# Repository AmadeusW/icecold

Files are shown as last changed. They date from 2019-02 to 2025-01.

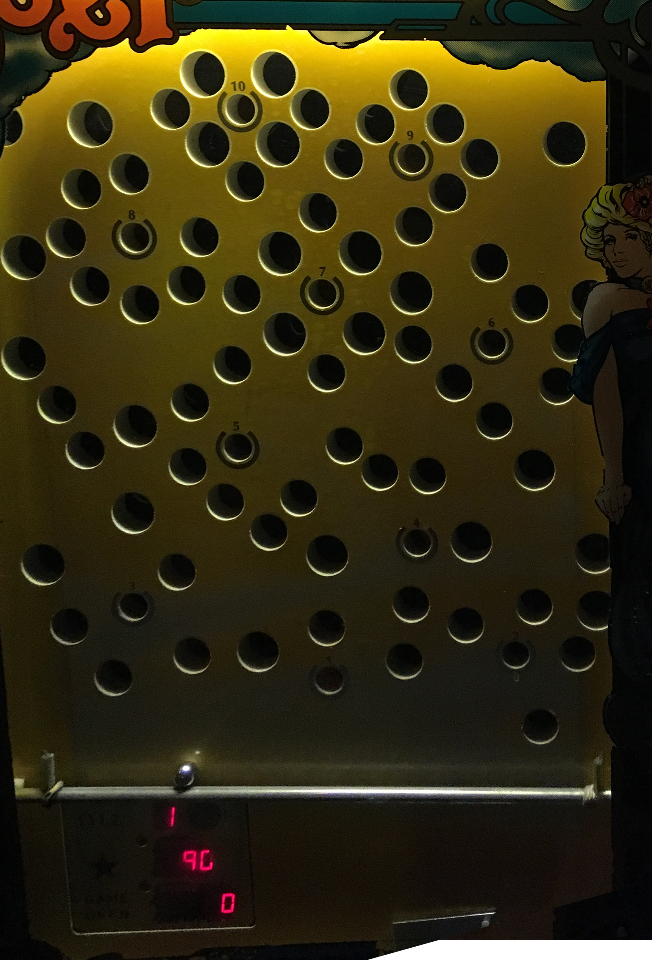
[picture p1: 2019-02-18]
web-prototype/holes.jpg

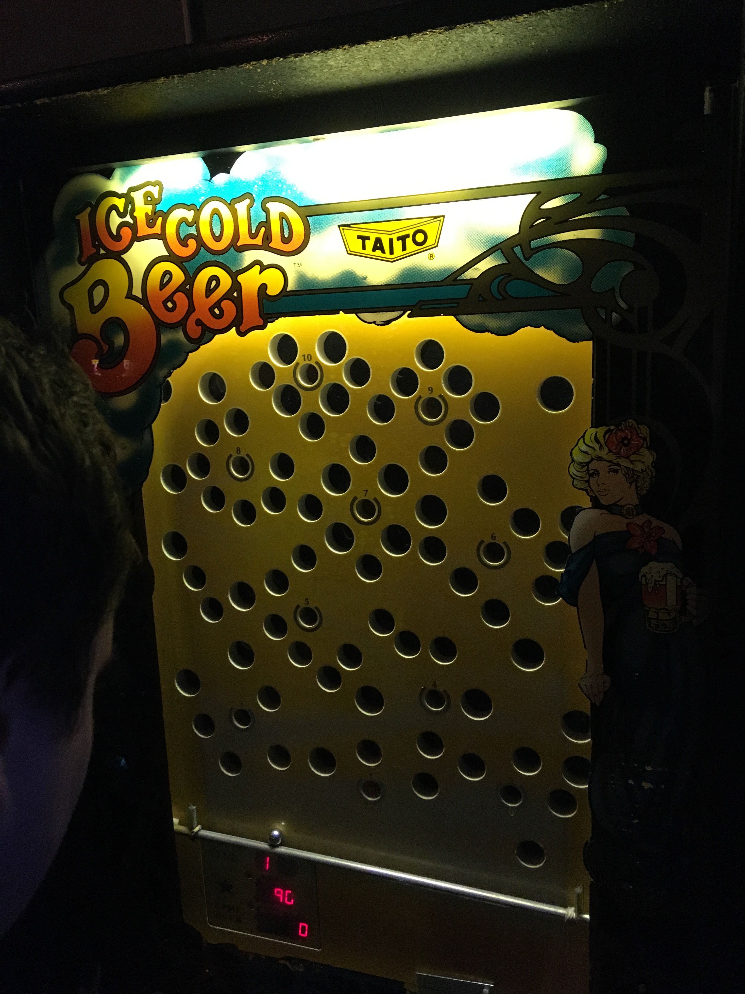
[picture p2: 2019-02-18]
misc/orignal photo.JPG

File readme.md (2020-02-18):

# Ice Cold Beer

**Ice Cold Beer** is an 1983 arcade by Taito.
Read more at [arcade-museum.com](https://www.arcade-museum.com/game_detail.php?game_id=10592)
See [picture](https://raw.githubusercontent.com/AmadeusW/icecold/master/misc/orignal%20photo.JPG)

# DIY Arcade

I'm building a physical arcade inspired by Ice Cold Beer.
See the [`program`](https://github.com/AmadeusW/icecold/tree/master/program) directory for microcontroller code and `printing` directory for 3D printed parts

# Virtual rendition

[Play now](https://amadeusw.github.io/icecold/web-prototype)

### Objective

* Insert the ball into the highlighted socket
* 🍺

### Controls

| Left | Right | |
|-|-|-|
| ↕ W/S | up/down ↕ | *Classic* |
| ↕ W/S | U/J ↕ | *Narrow* |
| ↕ W/S | I/J ↕ | *Narrow* |
| ↕ D/S | K/J ↕ | *VIM* |

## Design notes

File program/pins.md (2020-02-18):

# Pins

## Input

* 2 - Joystick L
* 2 - Joystick R
* 1 - Sensor Scored
* 1 - Sensor Lost
* 6 - Limiters

## Output

* 7 - Motor driver
* 2 - shift register
* ? - RGB strand

### Shift register
* 10 - Lives indicator
* 10 - Level indicator
* 10 - Target LEDs

### Parallel to Serial for input
* 1 - Sensor scored
* 1 - Sensor Lost
* 6 - Limiters

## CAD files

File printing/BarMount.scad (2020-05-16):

Gap = 0.2;
$fn = 72;

BarMount();

module BarMount() {
    RodThickness = 1.75 + Gap;
    RodDepth = 13.85; // Measured 13.10, but let's keep it a bit wider
    
    BearingDiameter = 8.0;
    BearingLength = 15;
    
    ConnectorShift = 0.3;
    
    ConnectorWidth = RodThickness+8;
    ConnectorDepth = RodDepth+5;
    
    CornerRadius = 1;
    
    intersection() {
        translate([0,0,ConnectorShift])
            cube([200,200,BearingDiameter - 2 * ConnectorShift], center=true);
        difference() {
            union () {
                rotate([0,-90,0])
                    cylinder(r = BearingDiameter/2, h = BearingLength);
                
                rotate([0,-90,0])
                    cylinder(r = BearingDiameter/2,
                             h = 5);
                
                linear_extrude(height=BearingDiameter, center=true)
                    offset(r=CornerRadius)
                        polygon([[CornerRadius, -ConnectorWidth/2 + CornerRadius],
                                 [ConnectorDepth - CornerRadius,
                                  -ConnectorWidth/2 + CornerRadius],
                                 [ConnectorDepth - CornerRadius,
                                  ConnectorWidth/2 - CornerRadius],
                                 [CornerRadius,
                                  ConnectorWidth/2 - CornerRadius]]);
            }
            
            rotate([0,0,2])
                union () {
                    translate([ConnectorDepth/2,0,0])
                        cube([RodDepth, RodThickness, 100], center = true);
            }
        }
    }    
}

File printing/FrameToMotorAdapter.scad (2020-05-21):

Gap = 0.2;
$fn = 72;

FrameToMotorAdapter();

module FrameToMotorAdapter() {
    Padding = 3.0;

    MotorInnerRadius = 13.0;
    MotorBraceRadius = MotorInnerRadius + Padding;

    SupportHeight = 6.0;
    MotorRadius = 26.0;

    HeadDiameter = 11.0;
    HeadHeight = 4.5 + Gap;

    ThreadDiameter = 6.6 + Gap; // I measured 6.2, but RodToBearingCoupling uses 6.5 for a snug fit
    ThreadHeight = 2.0;

    FrameAdapterWidth = HeadDiameter + 2*Padding;
    FrameAdapterLength = 32;
    FrameAdapterHeight = ThreadHeight + HeadHeight;

    BearingAdapterOffset = MotorRadius + FrameAdapterHeight; // Center of the rod
    BearingAdapterShift = 0;

    MountingNutOffset = 20.4;
    MountingNutRadius = 2.1; // actually 1.925, so 2.1 includes a gap

    ToTheSky = 50;

    union() {
        // Frame adapter
        difference() {
            cube([FrameAdapterLength, FrameAdapterWidth, FrameAdapterHeight]);

            // Volume of the nut head
            translate([0, Padding, ThreadHeight])
                cube([FrameAdapterLength, HeadDiameter, HeadHeight]);

            // Volume of the nut thread
            translate([0, Padding + (HeadDiameter - ThreadDiameter)/2, 0])
                cube([FrameAdapterLength, ThreadDiameter, ThreadHeight]);
        }

        // Motor housing adapter
        rotate([0, -90, 0])
        translate([BearingAdapterOffset, FrameAdapterWidth/2, -FrameAdapterLength])
        difference() {
            union()
            {
                // Resting arm
                translate([-BearingAdapterOffset/2, 0, 0])
                linear_extrude(height = SupportHeight, center = true)
                    polygon(points = [
                    [-BearingAdapterOffset/2, -FrameAdapterWidth/2],
                    [BearingAdapterOffset/2, -MotorRadius],
                    [BearingAdapterOffset/2, MotorRadius],
                    [-BearingAdapterOffset/2, FrameAdapterWidth/2],
                    ]);
            }
            union() {
                // Volume of motor housing
                cylinder(r = MotorRadius, h=SupportHeight, center=true);
            }
        }

        // Motor adapter
        rotate([0, -90, 0])
        translate([BearingAdapterOffset, FrameAdapterWidth/2, -BearingAdapterShift +SupportHeight/2])
        difference() {
            union()
            {
                // Bearing adapter
                difference()
                {
                    cylinder(r = MotorBraceRadius, h=SupportHeight, center=true);
                    // Remove top half (-Padding)
                    translate([-Padding, -ToTheSky/2, -ToTheSky/2])
                        cube([ToTheSky, ToTheSky, ToTheSky]);
                }
                
                // Connection to frame adapter
                p1 = RRTangent([BearingAdapterOffset/2,
                                -(MountingNutOffset+MountingNutRadius*.5)],
                               [-BearingAdapterOffset/2, -FrameAdapterWidth/2],
                               MountingNutRadius + Padding, 0, 1);

                p2 = RRTangent([BearingAdapterOffset/2,
                                (MountingNutOffset+MountingNutRadius*0.5)],
                               [-BearingAdapterOffset/2, FrameAdapterWidth/2],
                               MountingNutRadius + Padding, 0, -1);

                translate([-BearingAdapterOffset/2, 0, 0])
                linear_extrude(height = SupportHeight, center = true)
                    polygon(points = [
                    [-BearingAdapterOffset/2, -FrameAdapterWidth/2],
                    p1,
                    [BearingAdapterOffset/2,-(MountingNutOffset+MountingNutRadius*.5)],
                    [BearingAdapterOffset/2,(MountingNutOffset+MountingNutRadius*.5)],
                    p2,
                    [-BearingAdapterOffset/2, FrameAdapterWidth/2],
                    ]);

                // Mounting nut support
                translate([0, MountingNutOffset, 0])
                hull()
                {
                    translate([0, -MountingNutRadius/2, 0])
                        cylinder(r = MountingNutRadius + Padding, h=SupportHeight, center=true);
                    translate([0, MountingNutRadius/2, 0])
                        cylinder(r = MountingNutRadius + Padding, h=SupportHeight, center=true);
                }
                translate([0, -MountingNutOffset, 0])
                hull()
                {
                    translate([0, -MountingNutRadius/2, 0])
                        cylinder(r = MountingNutRadius + Padding, h=SupportHeight, center=true);
                    translate([0, MountingNutRadius/2, 0])
                        cylinder(r = MountingNutRadius + Padding, h=SupportHeight, center=true);
                }
            }
            union() {
                // Volume of motor
                translate([0, 0, 0])
                    cylinder(r = MotorInnerRadius + Gap, h=SupportHeight, center=true);

                // Mounting nuts
                translate([0, MountingNutOffset, 0])
                hull()
                {
                    translate([0, -MountingNutRadius/2, 0])
                        cylinder(r = MountingNutRadius, h=SupportHeight, center=true);
                    translate([0, MountingNutRadius/2, 0])
                        cylinder(r = MountingNutRadius, h=SupportHeight, center=true);
                }
                    
                translate([0, -MountingNutOffset, 0])
                hull()
                {
                    translate([0, -MountingNutRadius/2, 0])
                        cylinder(r = MountingNutRadius, h=SupportHeight, center=true);
                    translate([0, MountingNutRadius/2, 0])
                        cylinder(r = MountingNutRadius, h=SupportHeight, center=true);
                }
            }
        }
    }
}

// find p that is r1 from p1 and on a line that
// passes r1 from p1 and p2 from p2.
function RRTangent(p1, p2, r1, r2, s) =
     let(dx = (p2[0] - p1[0]))
     let(dy = (p2[1] - p1[1]))
     let(distance2 = dx*dx + dy*dy)
     let(distance = sqrt(distance2))
     let(nx = dx / distance)
     let(ny = dy / distance)
     let(cosA = (r1-r2)/distance)
     let(sinA = sqrt(1-cosA*cosA))
        [p1[0] + (cosA * r1) * nx - s * (sinA * r1) * ny,
         p1[1] + (cosA * r1) * ny + s * (sinA * r1) * nx];

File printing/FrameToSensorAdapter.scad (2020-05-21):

Gap = 0.2;
$fn = 72;

FrameToSensor();

module FrameToSensor() {
    Padding = 3.0;

    HeadDiameter = 11.0;
    HeadHeight = 4.5 + Gap;

    ThreadDiameter = 6.6 + Gap; // I measured 6.2, but RodToBearingCoupling uses 6.5 for a snug fit
    ThreadHeight = 2.0;

    FrameAdapterWidth = HeadDiameter + 2*Padding;
    FrameAdapterLength = 32;
    FrameAdapterHeight = ThreadHeight + HeadHeight;

    MotorRadius = 26.0;
    BearingAdapterOffset = MotorRadius + FrameAdapterHeight;
    BearingAdapterShift = 0;

    MountRadius = 1.0; // it's a 2mm screw
    MountDistance = 12.65;
    MountOffsetFromCenter = MountDistance / 2;
    MountHeight = FrameAdapterHeight + MountRadius + Padding; // As low as possible

    Width = MountDistance + (MountRadius*2 + Padding)*2;
    Depth = 4; // arbitrary
    Height = Width + FrameAdapterHeight;
    ToTheSky = 50;

    union() {
        // Frame adapter
        difference() {
            cube([FrameAdapterLength, FrameAdapterWidth, FrameAdapterHeight]);

            // Volume of the nut head
            translate([0, Padding, ThreadHeight])
                cube([FrameAdapterLength + Gap, HeadDiameter, HeadHeight]);

            // Volume of the nut thread
            translate([0, Padding + (HeadDiameter - ThreadDiameter)/2, 0])
                cube([FrameAdapterLength + Gap, ThreadDiameter, ThreadHeight]);
        }

        // Sensor adapter
        rotate([0, -90, 0])
        translate([0, FrameAdapterWidth/2, Depth/2])
        difference() {
            union()
            {
                // Connection to frame adapter
                linear_extrude(height = Depth, center = true)
                    polygon(points = [
                    [0, -FrameAdapterWidth/2],
                    [Height/2, -Width/2],
                    [Height/2, Width/2],
                    [0, FrameAdapterWidth/2],
                    ]);
            }
            union() {
                // Volume of mount 1
                translate([MountHeight, -MountOffsetFromCenter, 0])
                hull()
                {
                    translate([0, -MountRadius/2, 0])
                        cylinder(r = MountRadius + Gap, h=ToTheSky, center=true);
                    translate([0, MountRadius/2, 0])
                        cylinder(r = MountRadius + Gap, h=ToTheSky, center=true);
                }

                // Volume of mount 2
                translate([MountHeight, MountOffsetFromCenter, 0])
                hull()
                {
                    translate([0, -MountRadius/2, 0])
                        cylinder(r = MountRadius + Gap, h=ToTheSky, center=true);
                    translate([0, MountRadius/2, 0])
                        cylinder(r = MountRadius + Gap, h=ToTheSky, center=true);
                }
            }
        }
    }
}

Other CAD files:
printing/NutToMotorSupport.scad
printing/FrameBearingAdapter.scad
printing/FrameToBearingLAdapter.scad
printing/Guide.scad
printing/RodConnect.scad
printing/RodCoupling.scad
printing/RodToMotorCoupling.scad
printing/dependencies/Pulley_T-MXL-XL-HTD-GT2_N-tooth.scad
printing/obsolete/FrameBearingAdapter.scad
printing/obsolete/prototypes.scad
printing/prototypes.scad

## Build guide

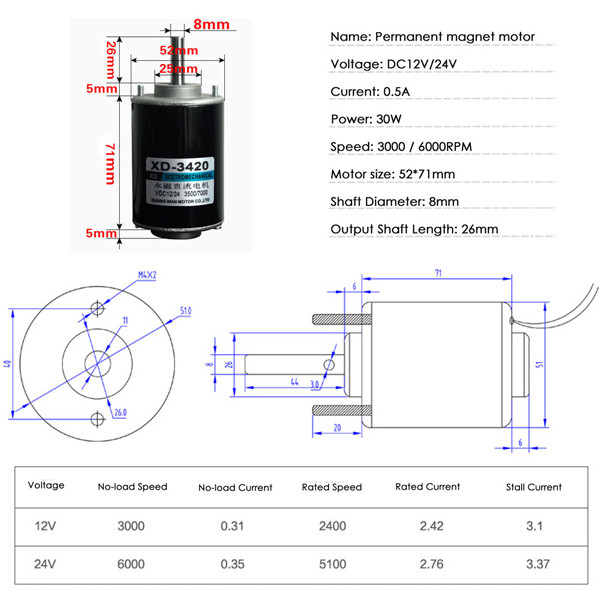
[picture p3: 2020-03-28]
printing/dependencies/xd-3420 dc motorjpg.jpg

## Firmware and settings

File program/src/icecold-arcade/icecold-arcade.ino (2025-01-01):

// Entry point for the code running on the microcontroller

#include "../common/composition.h"
#include "../common/GameController.h"
#include "../common/GameEngine.h"
#include "../common/GameState.h"

#include "../common/module.h"
#include "../common/modules/LedModule.h"

GameEngine* engine;

void setup() {
    // Example usage
    LedModule ledModule1(13);
    LedModule ledModule2(14);
    Module* modules[] = {&ledModule1, &ledModule2};
    Composition composition(modules, 2);
    GameController controller;
    GameState state;
    engine = new GameEngine(composition, controller, state);
    engine->setup();
}

void loop() {
    engine->loop();
}

int main()
{
    setup();
    while (true) {
        loop();
    }
}

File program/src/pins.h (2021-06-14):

#ifndef pins_h
#define pins_h

#include "Arduino.h"

#define PinMotorAIn1 1
#define PinMotorAIn2 1
#define PinMotorPWMA 1
#define PinMotorBIn1 1
#define PinMotorBIn2 1
#define PinMotorPWMB 1
#define PinMotorSTBY 0
#define PinJoyAUp 4 // green
#define PinJoyADown 5 // yellow
#define PinJoyBUp 6 // blue
#define PinJoyBDown 7 // yellow
#define PinSerialClock 8 // orange
#define PinSerialLatch 9 // orange
#define PinBallAtTarget 10 // white
#define PinBallAtBottom 11 // red
#define PinSerialData 12 // green
#define PinDebugLed 13
#define PinRange0Enable 16 // Yellow
#define PinRange1Enable 17 // Yellow
#define PinI2CData 18 // White
#define PinI2CClock 19 // Orange
// Future:
// #define PinServo X

#endif

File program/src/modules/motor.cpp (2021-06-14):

#include "Arduino.h"
#include "motor.h"
#include "../pins.h"

void Motor::Setup()
{
    pinMode(PinMotorAIn1, OUTPUT);
    pinMode(PinMotorAIn2, OUTPUT);
    pinMode(PinMotorPWMA, OUTPUT);
    pinMode(PinMotorSTBY, OUTPUT);

    digitalWrite(PinMotorSTBY, HIGH);

    Serial.println("Setup complete: Motor");
}

void Motor::Output(int tick)
{
    if (this->speedLeft == 0)
    {
        digitalWrite(PinMotorAIn1, HIGH);
        digitalWrite(PinMotorAIn2, HIGH);
    }
    else if (this->speedLeft > 0)
    {
        digitalWrite(PinMotorAIn1, HIGH);
        digitalWrite(PinMotorAIn2, LOW); 
        analogWrite(PinMotorPWMA, this->speedLeft);
    }
    else
    {
        digitalWrite(PinMotorAIn1, LOW);
        digitalWrite(PinMotorAIn2, HIGH); 
        analogWrite(PinMotorPWMA, -(this->speedLeft));
    }

    if (this->speedRight == 0)
    {
        digitalWrite(PinMotorBIn1, HIGH);
        digitalWrite(PinMotorBIn2, HIGH);
    }
    else if (this->speedRight > 0)
    {
        digitalWrite(PinMotorBIn1, HIGH);
        digitalWrite(PinMotorBIn2, LOW); 
        analogWrite(PinMotorPWMB, this->speedRight);
    }
    else
    {
        digitalWrite(PinMotorBIn1, LOW);
        digitalWrite(PinMotorBIn2, HIGH); 
        analogWrite(PinMotorPWMB, -(this->speedRight));
    }
}

void Motor::Brake()
{
    this->speedLeft = 0;
    this->speedRight = 0;
}

void Motor::MoveLeft(bool up, int speed)
{
    this->speedLeft = up ? speed : -speed;
}

void Motor::MoveRight(bool up, int speed)
{
    this->speedRight = up ? speed : -speed;
}

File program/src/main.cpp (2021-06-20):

#include "Arduino.h"
#include "pins.h"
#include "handler.h"
#include "state.h"
#include "composition.h"

// Define externs declared in state.h
State state = uninitialized;
int turn = 0;
Composition composition;

void setup()
{
  Serial.begin(115200); // set up debugging
  while (! Serial) { delay(1); }
  Serial.println("Hello World!");

  Serial.println("Composing modules...");
  composition.Compose(); // Compose modules and handlers
  Serial.println("Setting up modules...");
  composition.Setup(); // Setup all modules and handlers
  Serial.println("Setup complete.");
  delay(50);
  state = idle; // running
}

void updateState()
{
    Handler* handler = composition.GetHandler(state);
    if (handler == 0)
    {
        Serial.print("UpdateState: no handler for ");
        Serial.println(state);
    }
    else
    {
        state = handler->SetState(state, turn);
    }
}

void printCurrentState()
{
    Serial.printf("[%d]", turn);
    switch (state) {
        case uninitialized:      Serial.print("uninit"); break;
        case newGame:            Serial.print(" new "); break;
        case shooter:            Serial.print("shoot "); break;
        case playfield:          Serial.print(" play "); break;
        case outlane:            Serial.print(" out  "); break;
        case gameOverWon:        Serial.print(" won  "); break;
        case gameOverLost:       Serial.print(" lost "); break;
        default:                 Serial.print("ERROR "); break;
    }
}

void act()
{
    printCurrentState();

    Handler* handler = composition.GetHandler(state);
    if (handler == 0)
    {
        Serial.print("Act: no handler for ");
        Serial.println(state);
    }
    else
    {
        handler->Act(state, turn);
    }
}

void finishTurn()
{
    delay(50); // TODO: delay as many ms as necessary to achieve 50ms per turn
    turn++;
}

void loop()
{
    composition.Input();
    updateState();
    act();
    finishTurn();
}

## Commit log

2020-01-10 basic motor test code
2020-01-10 3d print prototypes from 2019.12.18
    [prototypes.scad]
2020-01-10 make adjustments to 3d prints
    [prototypes.scad]
2020-01-10 add another kind of coupling
    [prototypes.scad]
2020-01-10 slightly tilt the bar
    [prototypes.scad]
2020-01-29 Rod to Bearing and Motor couplings
    [prototypes.scad]
2020-01-29 control motor with joystick
2020-01-29 correct dimensions
    [prototypes.scad]
2020-01-29 ensure 45 degrees in the inner shaft
    [prototypes.scad]
2020-01-30 add supports to the RodToMotorCoupling
    [prototypes.scad]
2020-01-31 Revert "add supports to the RodToMotorCoupling"
    This reverts commit 98650b81d300b771f839721ca990d59cf2530ce4.
    [prototypes.scad]
2020-01-31 make RodToBearingCoupling smaller
    [prototypes.scad]
2020-01-31 make bearingDiameter smaller
    [prototypes.scad]
2020-02-01 attempt at moving servo
2020-02-04 Add cross section helper
    [prototypes.scad]
2020-02-17 fixes pins values for state transitions
    [composition.cpp, main.cpp, pins.h]
2020-03-19 add hide parameter to Helper module
    [prototypes.scad]
2020-03-19 adds the Parametric Pulley dependency
    [Pulley_T-MXL-XL-HTD-GT2_N-tooth.scad]
2020-03-28 2020-03-20 printing
    [FrameBearingAdapter.scad, Pulley_T-MXL-XL-HTD-GT2_N-tooth.scad, RodConnect.scad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]
2020-03-28 2020-03-28 prototypes
    [FrameToBearingLAdapter.scad, FrameToMotorAdapter.scad, Guide.scad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]
2020-03-29 add FrameToSensorAdapter
    [FrameToSensorAdapter.scad]
2020-03-29 add FrameToMotorSupport
    [FrameToMotorSupport.scad]
2020-04-03 remove whitespace
    [FrameToMotorSupport.scad]
2020-04-03 makes motor a module
2020-04-15 fixes down and scored state transitions
    [composition.cpp, defaultHandler.cpp, scoreHandler.cpp]
2020-04-16 add the score sensor
2020-04-18 correct the Shift Register output
    [display.cpp]
2020-05-14 prototyping the led bar connected to serial port
2020-05-14 update FrameToMotorAdapter distances and sizes
    [FrameToMotorAdapter.scad]
2020-05-14 update FrameToMotorSupport even though I probably wont use it
    [FrameToMotorSupport.scad]
2020-05-14 mind the gap!
    [FrameToMotorAdapter.scad]
2020-05-14 replace FrameToMotorSupport with lightweight NutToMotorSupport
    [FrameToMotorSupport.scad, NutToMotorSupport.scad]
2020-05-14 add RodToMotorCoupling, from prototypes.scad, updated
    [RodToMotorCoupling.scad]
2020-05-14 motor coupling works under new arrangement
    [RodToMotorCoupling.scad]
2020-05-15 I think I fixed RodToMotorCoupling in motor mode
    [RodToMotorCoupling.scad]
2020-05-15 rename to RodCoupling, remove RodToBearingCoupling
    [RodCoupling.scad, RodToBearingCoupling.scad]
2020-05-15 softer bottom edge
    [RodCoupling.scad]
2020-05-15 display both rod couplings
    [RodCoupling.scad]
2020-05-15 rename RodConnect to BarMount. Still have work to do on that one
    [BarMount.scad]
2020-05-15 reworked the guide
    [Guide.scad]
2020-05-16 verified dimensions of the guide
    [Guide.scad]
2020-05-16 Add supports at an angle
    [Guide.scad]
2020-05-16 update the FrameToSensorAdapter to fit the laser range meter
    [FrameToSensorAdapter.scad]
2020-05-16 updated the BarMount
    [BarMount.scad]
2020-05-21 improve incorrect measurement
    [FrameToSensorAdapter.scad]
2020-05-21 fix orientation of NutToMotorSupport
    [NutToMotorSupport.scad]
2020-05-21 apply DPugh's changes
    [FrameToMotorAdapter.scad]
2020-05-21 fix measurements of Guide
    [Guide.scad]
2020-05-21 improve bolt channels and tower shape
    [Guide.scad]
2020-05-21 remove old code
    [Guide.scad]
2020-05-21 improve measurements
    [Guide.scad]
2020-05-21 reduce the Top Height of Rod Coupling
    [RodCoupling.scad]
2020-05-22 fix display, add test pattern
    [display.cpp]
2020-05-22 move FrameBearingAdapter to the obsolete dir
    [FrameBearingAdapter.scad]
2020-05-22 move Prototypes to the obsolete dir
    [prototypes.scad]
2020-06-01 hooks up the i2c 7segment display
2020-06-07 support two range modules, gracefully handle failure
    [defaultHandler.cpp, pins.h, range.cpp]
2020-06-08 use correct voltages for the range meter
    [range.cpp]
2020-06-08 an attempt to get two sensors working
2020-06-09 fix the multiple range sensors experiment
    [multiple_vl53l0x.ino]
2020-06-09 fix the multiple range sensors program
    [range.cpp]
2021-06-14 add joystick, ball sensor. remove pins.cpp
2024-12-31 composition, sample modules
2025-01-01 trying to get the arduino part to build
